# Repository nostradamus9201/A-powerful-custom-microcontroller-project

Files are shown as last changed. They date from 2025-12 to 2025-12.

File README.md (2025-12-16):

# A-powerful-custom-microcontroller-project
An Rp2354B based microcontroller with more storage and more ports, designed and traced by yours truly.
It consists of 6 layers, one male and one female usb c port, and onboard memory with 2 extra 16mb flash chips.

#Pitch:
Ever tired of having to find an outdated usb micro-b connector to connect to your devboard ?
Fear not.
Ever tired of having too little flash memory ?
Feaaar noot.
Ever tired of ANY issue with your rp2350 devboards ?
The "Just a better rp2354 devboard"™   is here to fix all of them.
(Not guranteed to fix all of your problems, no refunds)

# Part Images and Schematics



All layers combined



Front layer



GND layer



3v3 power layer



1v1 & misc. layer



Misc. layer



Back layer



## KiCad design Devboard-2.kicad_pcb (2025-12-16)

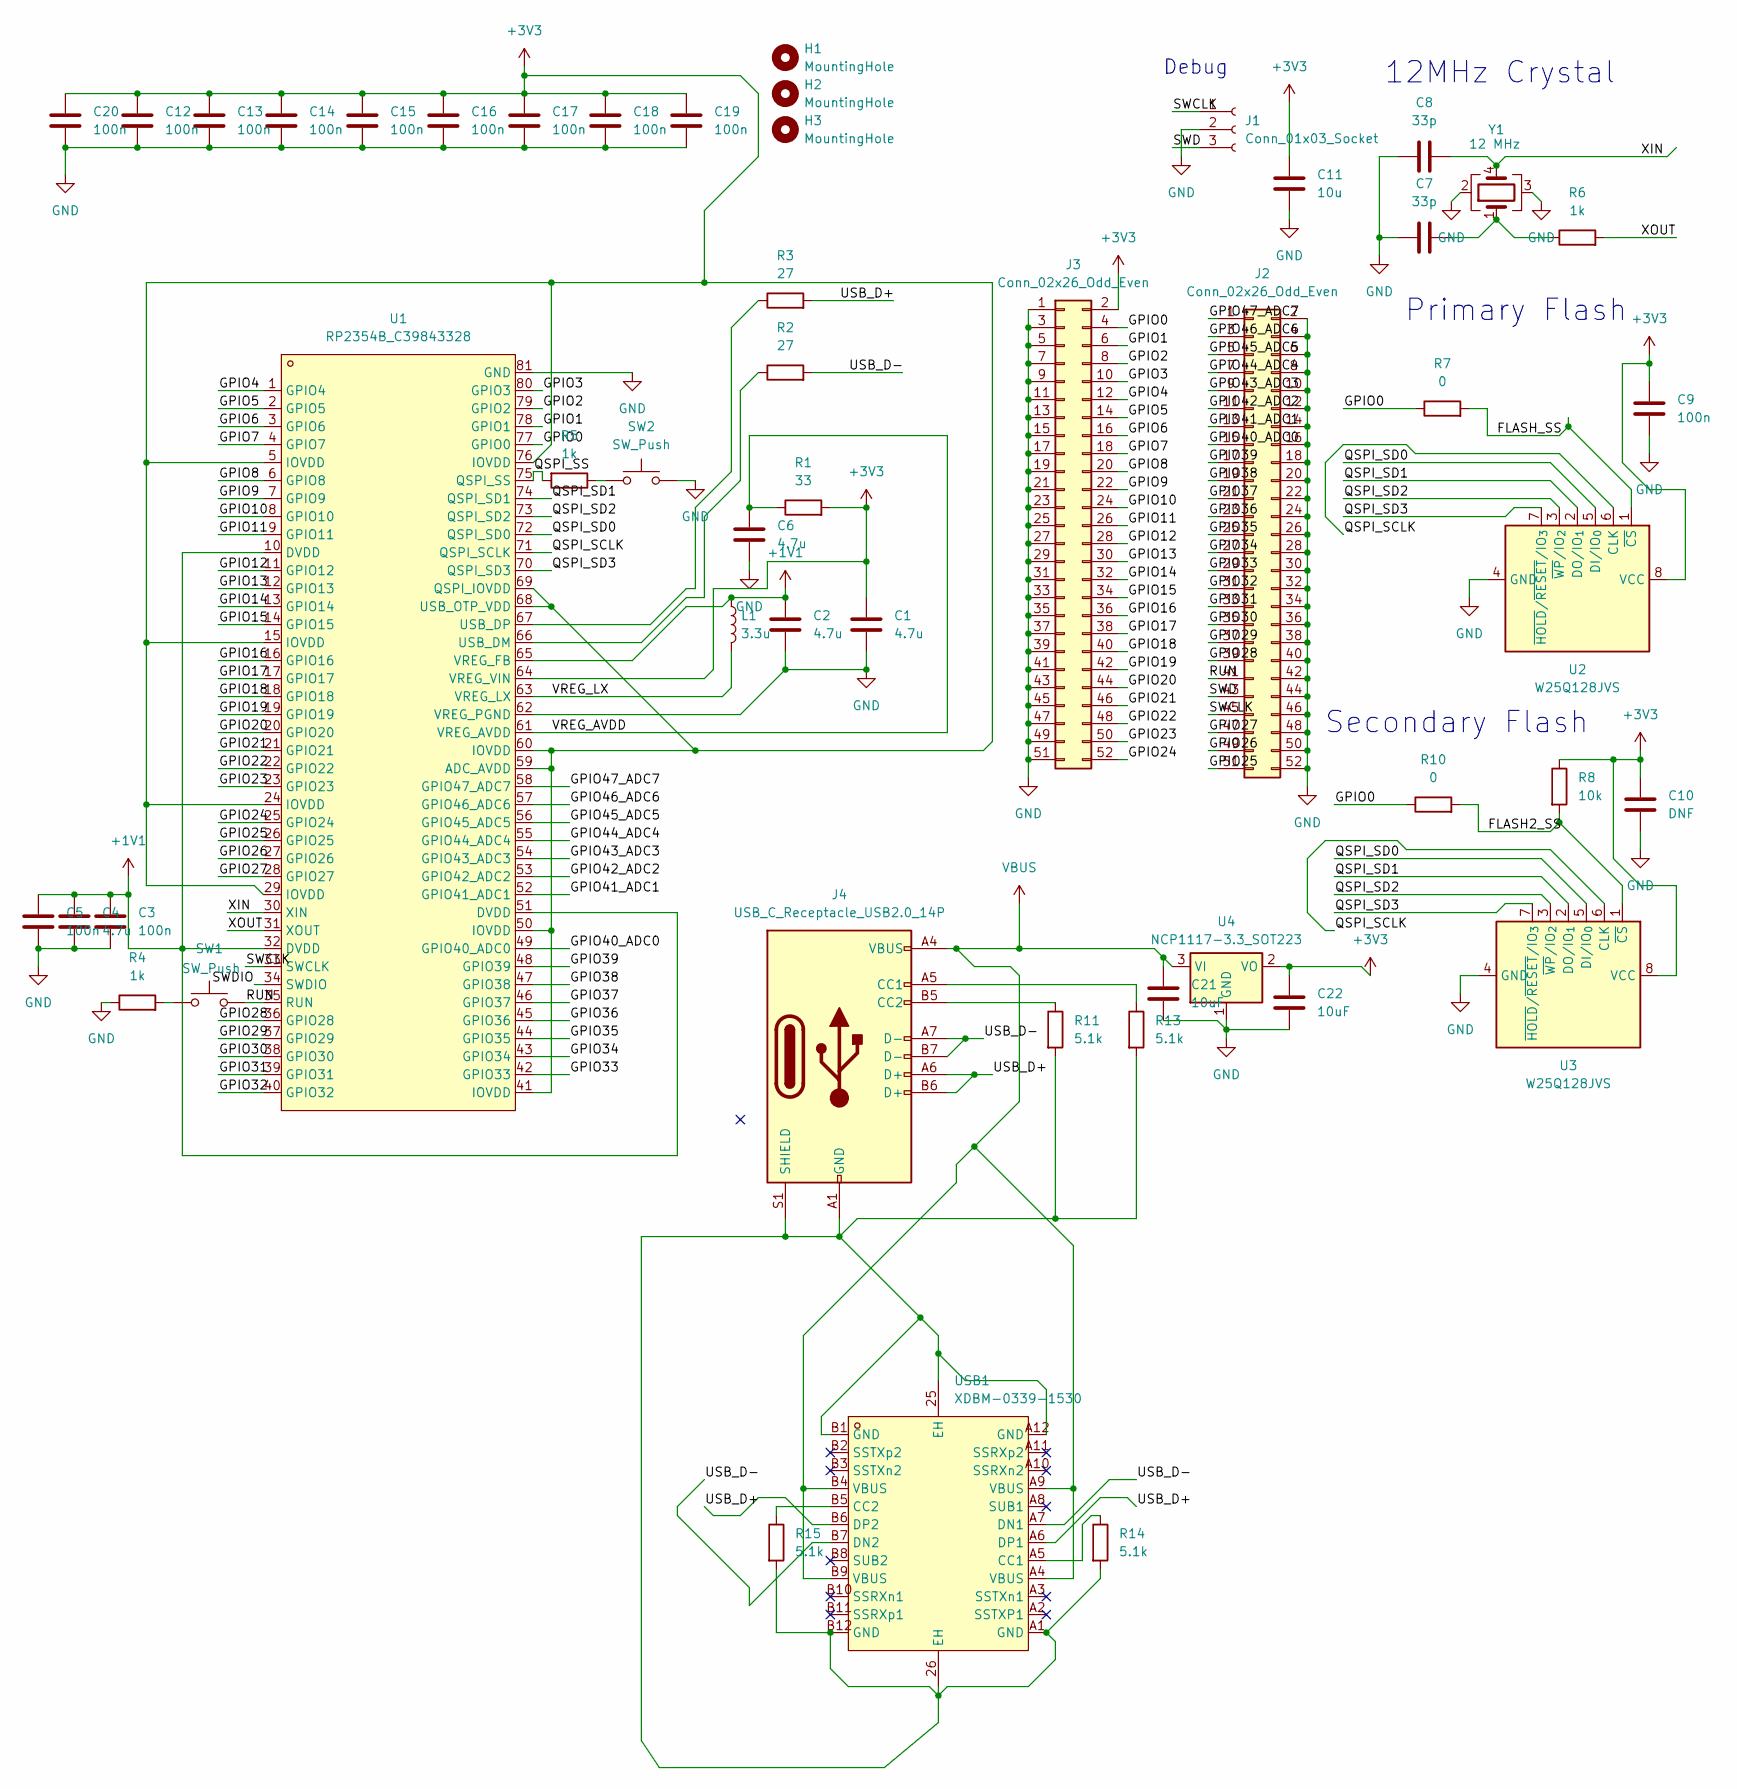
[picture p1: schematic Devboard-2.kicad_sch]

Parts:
C1, C2, C4, C6: 4.7u; C_0603_1608Metric
C3, C5, C9, C12, C13, C14, C15, C16, C17, C18, C19, C20: 100n; C_0402_1005Metric
C7, C8: 33p; C_0402_1005Metric
C10: DNF; C_0402_1005Metric
C11: 10u; C_0603_1608Metric
C21, C22: 10uF; C_0603_1608Metric
H1, H2, H3: MountingHole; MountingHole_2.1mm
J1: Conn_01x03_Socket; PinHeader_1x03_P2.54mm_Vertical
J2, J3: Conn_02x26_Odd_Even; PinHeader_2x26_P2.54mm_Vertical
J4: USB_C_Receptacle_USB2.0_14P; USB_C_Receptacle_HRO_TYPE-C-31-M-12
L1: 3.3u; C_0805_2012Metric
R1: 33; R_0402_1005Metric
R2, R3: 27; R_0402_1005Metric
R4, R5, R6: 1k; R_0402_1005Metric
R7, R10: 0; R_0402_1005Metric
R8: 10k; R_0402_1005Metric
R11, R13, R14, R15: 5.1k; R_0402_1005Metric
SW1, SW2: SW_Push; SW_Push_SPST_NO_Alps_SKRK
U1: RP2354B_C39843328; QFN-80_L10.0-W10.0-P0.40-TL-EP3.4; LCSC Part C39843328
U2, U3: W25Q128JVS; SOIC-8_5.3x5.3mm_P1.27mm
U4: NCP1117-3.3_SOT223; SOT-223-3_TabPin2
USB1: XDBM-0339-1530; USB-C-SMD_USB-3.1-C-TYPE; LCSC Part C7527710
Y1: 12 MHz; Crystal_SMD_3225-4Pin_3.2x2.5mm

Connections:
+1V1: C2.1, C3.1, C4.1, C5.1, L1.1, U1.10 (DVDD), U1.32 (DVDD), U1.51 (DVDD), U1.65 (VREG_FB)
+3V3: C1.1, C9.1, C10.1, C11.1, C12.1, C13.1, C14.1, C15.1, C16.1, C17.1, C18.1, C19.1, C20.1, C22.1, J3.2, R1.2, R8.1, U1.5 (IOVDD), U1.15 (IOVDD), U1.24 (IOVDD), U1.29 (IOVDD), U1.41 (IOVDD), U1.50 (IOVDD), U1.59 (ADC_AVDD), U1.60 (IOVDD), U1.64 (VREG_VIN), U1.68 (USB_OTP_VDD), U1.69 (QSPI_IOVDD), U1.76 (IOVDD), U2.8 (VCC), U3.8 (VCC), U4.2 (VO)
/FLASH2_SS: R8.2, R10.2, U3.1 (~CS)
/FLASH_SS: R7.2, U2.1 (~CS)
/GPIO0: J3.4, R7.1, R10.1, U1.77 (GPIO0)
/GPIO1: J3.6, U1.78 (GPIO1)
/GPIO2: J3.8, U1.79 (GPIO2)
/GPIO3: J3.10, U1.80 (GPIO3)
/GPIO4: J3.12, U1.1 (GPIO4)
/GPIO5: J3.14, U1.2 (GPIO5)
/GPIO6: J3.16, U1.3 (GPIO6)
/GPIO7: J3.18, U1.4 (GPIO7)
/GPIO8: J3.20, U1.6 (GPIO8)
/GPIO9: J3.22, U1.7 (GPIO9)
/GPIO10: J3.24, U1.8 (GPIO10)
/GPIO11: J3.26, U1.9 (GPIO11)
/GPIO12: J3.28, U1.11 (GPIO12)
/GPIO13: J3.30, U1.12 (GPIO13)
/GPIO14: J3.32, U1.13 (GPIO14)
/GPIO15: J3.34, U1.14 (GPIO15)
/GPIO16: J3.36, U1.16 (GPIO16)
/GPIO17: J3.38, U1.17 (GPIO17)
/GPIO18: J3.40, U1.18 (GPIO18)
/GPIO19: J3.42, U1.19 (GPIO19)
/GPIO20: J3.44, U1.20 (GPIO20)
/GPIO21: J3.46, U1.21 (GPIO21)
/GPIO22: J3.48, U1.22 (GPIO22)
/GPIO23: J3.50, U1.23 (GPIO23)
/GPIO24: J3.52, U1.25 (GPIO24)
/GPIO25: J2.51, U1.26 (GPIO25)
/GPIO26: J2.49, U1.27 (GPIO26)
/GPIO27: J2.47, U1.28 (GPIO27)
/GPIO28: J2.39, U1.36 (GPIO28)
/GPIO29: J2.37, U1.37 (GPIO29)
/GPIO30: J2.35, U1.38 (GPIO30)
/GPIO31: J2.33, U1.39 (GPIO31)
/GPIO32: J2.31, U1.40 (GPIO32)
/GPIO33: J2.29, U1.42 (GPIO33)
/GPIO34: J2.27, U1.43 (GPIO34)
/GPIO35: J2.25, U1.44 (GPIO35)
/GPIO36: J2.23, U1.45 (GPIO36)
/GPIO37: J2.21, U1.46 (GPIO37)
/GPIO38: J2.19, U1.47 (GPIO38)
/GPIO39: J2.17, U1.48 (GPIO39)
/GPIO40_ADC0: J2.15, U1.49 (GPIO40_ADC0)
/GPIO41_ADC1: J2.13, U1.52 (GPIO41_ADC1)
/GPIO42_ADC2: J2.11, U1.53 (GPIO42_ADC2)
/GPIO43_ADC3: J2.9, U1.54 (GPIO43_ADC3)
/GPIO44_ADC4: J2.7, U1.55 (GPIO44_ADC4)
/GPIO45_ADC5: J2.5, U1.56 (GPIO45_ADC5)
/GPIO46_ADC6: J2.3, U1.57 (GPIO46_ADC6)
/GPIO47_ADC7: J2.1, U1.58 (GPIO47_ADC7)
/QSPI_SCLK: U1.71 (QSPI_SCLK), U2.6 (CLK), U3.6 (CLK)
/QSPI_SD0: U1.72 (QSPI_SD0), U2.5 (DI/IO_{0}), U3.5 (DI/IO_{0})
/QSPI_SD1: U1.74 (QSPI_SD1), U2.2 (DO/IO_{1}), U3.2 (DO/IO_{1})
/QSPI_SD2: U1.73 (QSPI_SD2), U2.3 (~WP/IO_{2}), U3.3 (~WP/IO_{2})
/QSPI_SD3: U1.70 (QSPI_SD3), U2.7 (~HOLD/~RESET/IO_{3}), U3.7 (~HOLD/~RESET/IO_{3})
/QSPI_SS: R5.2, U1.75 (QSPI_SS)
/RUN: J2.41, SW1.2, U1.35 (RUN)
/SWCLK: J1.1, J2.45, U1.33 (SWCLK)
/USB_D+: J4.A6 (D+), J4.B6 (D+), R3.2, USB1.A6 (DP1), USB1.B6 (DP2)
/USB_D-: J4.A7 (D-), J4.B7 (D-), R2.2, USB1.A7 (DN1), USB1.B7 (DN2)
/VREG_AVDD: C6.1, R1.1, U1.61 (VREG_AVDD)
/VREG_LX: L1.2, U1.63 (VREG_LX)
/XIN: C8.2, U1.30 (XIN), Y1.4
unnamed: J4.A5 (CC1), R13.1
unnamed: J4.B5 (CC2), R11.1
unnamed: R4.2, SW1.1
unnamed: R5.1, SW2.1
unnamed: R2.1, U1.66 (USB_DM)
unnamed: R3.1, U1.67 (USB_DP)
unnamed: R14.1, USB1.A5 (CC1)
unnamed: R15.1, USB1.B5 (CC2)
VBUS: C21.1, J4.A4 (VBUS), J4.A9 (VBUS), J4.B4 (VBUS), J4.B9 (VBUS), U4.3 (VI), USB1.A4 (VBUS), USB1.A9 (VBUS), USB1.B4 (VBUS), USB1.B9 (VBUS)

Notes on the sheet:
Debug
12MHz Crystal
Secondary Flash
Primary Flash

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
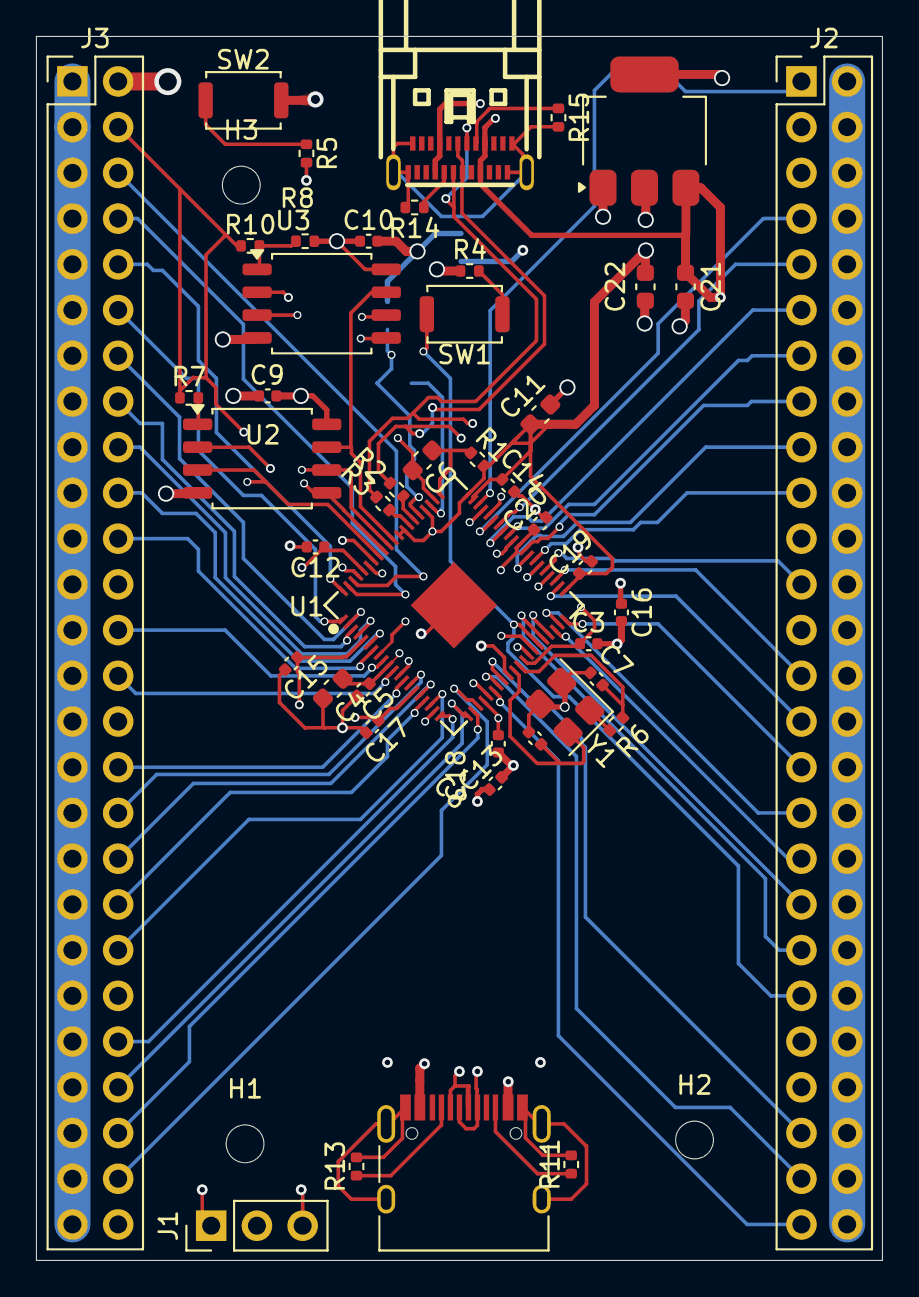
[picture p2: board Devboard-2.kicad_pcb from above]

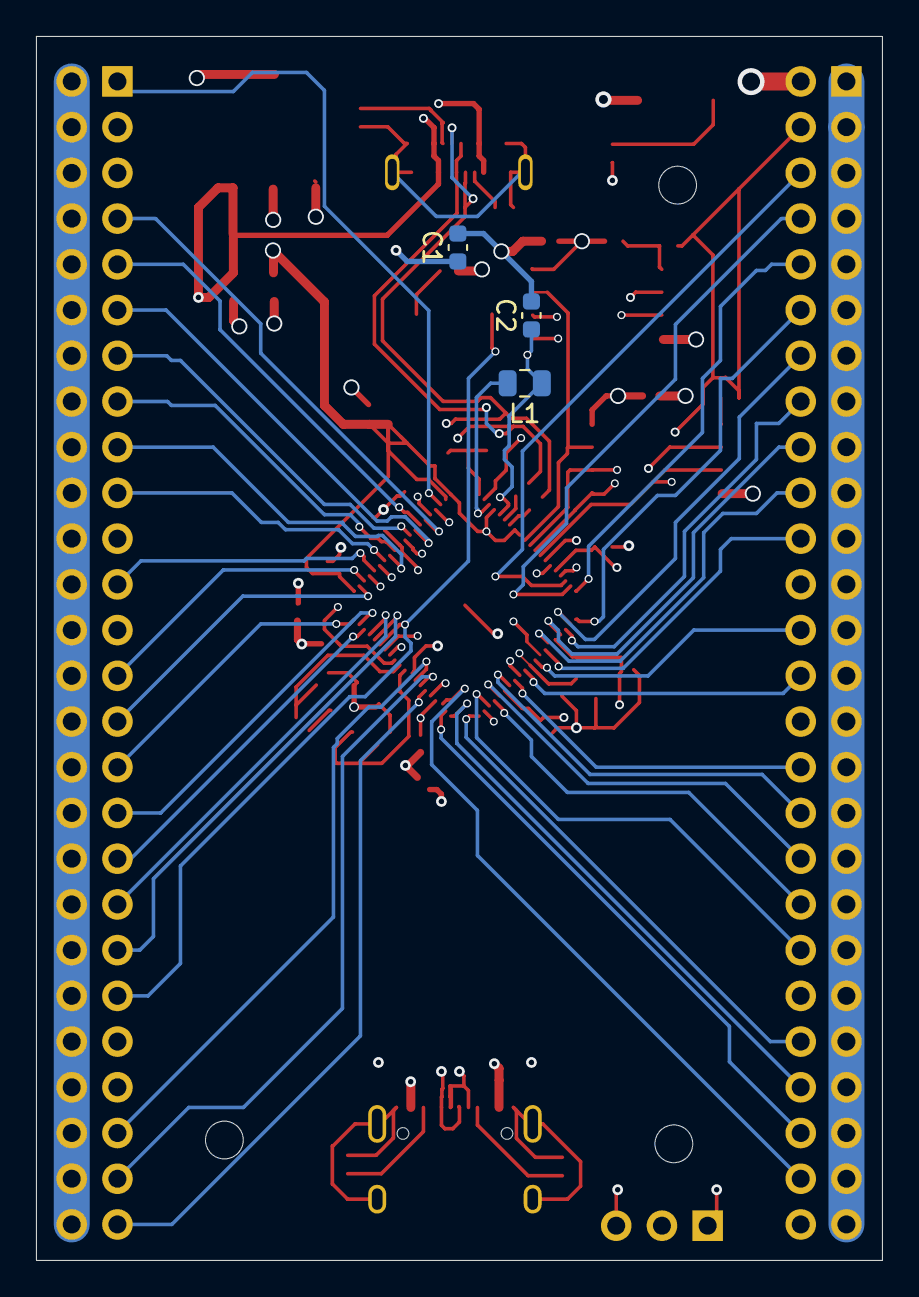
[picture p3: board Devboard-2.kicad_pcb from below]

Board: 6 copper layers, 47.0 x 68.0 mm, 51 parts (3 on the bottom side), 79 nets.
